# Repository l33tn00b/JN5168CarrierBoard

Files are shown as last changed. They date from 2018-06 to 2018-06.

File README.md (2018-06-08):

# JN5168CarrierBoard
Carrier Board for JN5168 Module with Reset and Programming Button; Step-Down Regulator (24V DC input).

This is a carrier board for JN5168 ZigBee modules. All pins are broken out. Reset and Programming buttons are provided. The better part of the carrier module is occupied by parts for the step-down voltage regulator. Reverse input polarity protection is provided (except for the input buffer capacitor, if placed). 

Above stated imput voltage limit (24V) depends on the FET used for polarity protection and the voltage rating of the input buffer capacitor. The chosen FET for polarity protection is rated for up to 30V. Omitting or replacing this FET and placing an appropriate buffer capacitor allow for input voltages up to the limit of the DC-DC step-down regulator, i.e. 45V.

Voltage is supplied via RIACON Connectors (screw terminals that may be pulled off from their pins).

Here is a representation created by KiCAD:

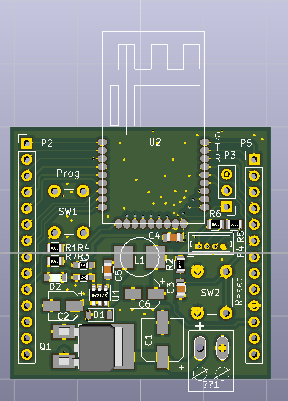
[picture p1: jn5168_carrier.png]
JN5168 Carrier Board Rendered by KiCAD Render of JN5168 Carrier Board


This is the schematic:
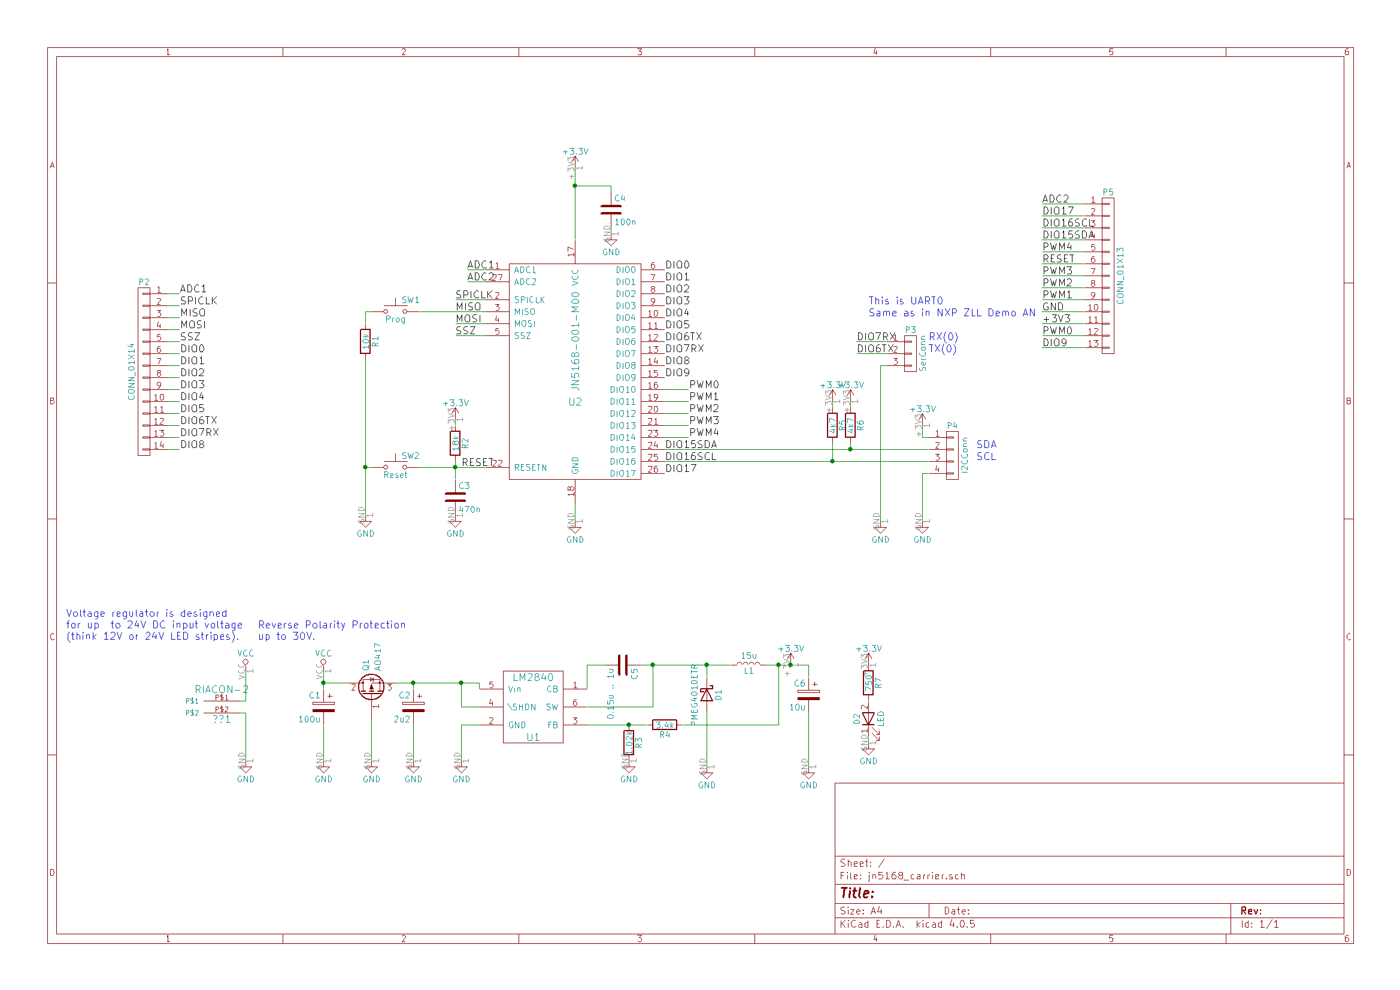
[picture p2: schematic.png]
JN5168 Carrier Board Schematic Schematic of JN5168 Carrier Board


There you go, a real PCB (to the left):
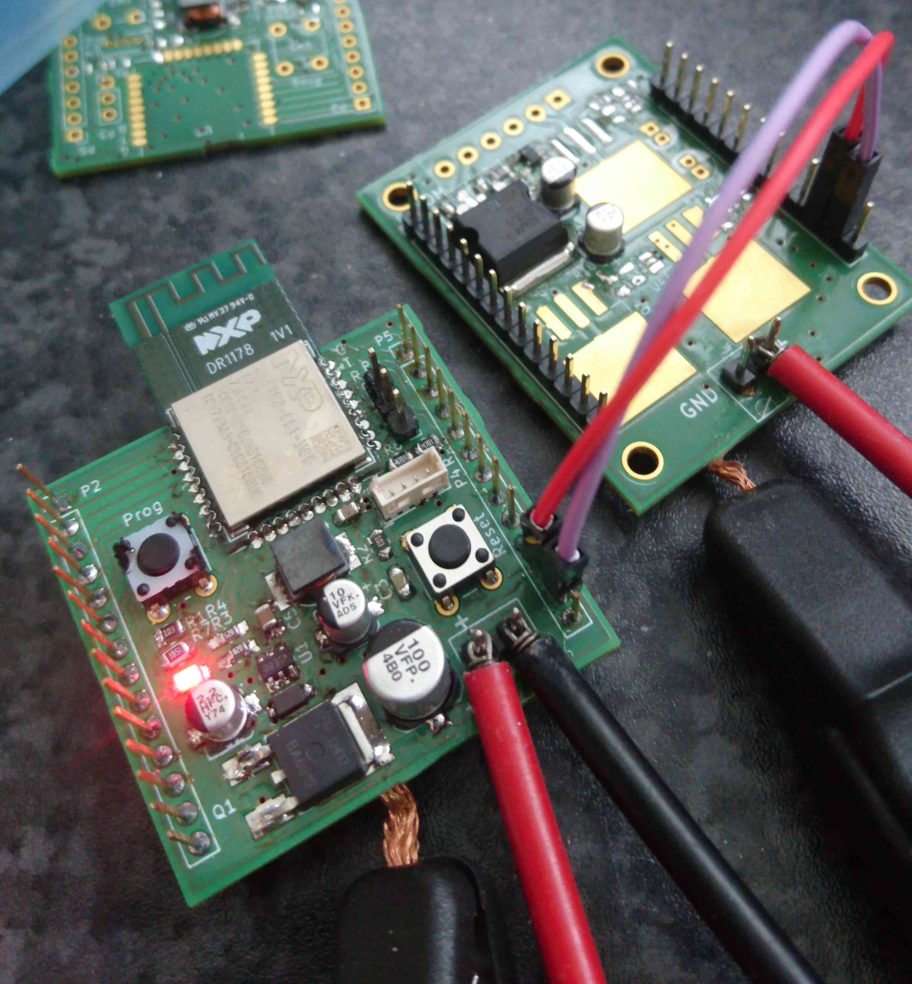
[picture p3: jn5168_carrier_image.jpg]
JN5168 Carrier Board Image Image of JN5168 Carrier Board


On the above picture you might realize the voltage supply (red and black) is done via clamps instead of the screw terminal: This is due to the RIACON screw terminal that can just be pulled off the solder pins.

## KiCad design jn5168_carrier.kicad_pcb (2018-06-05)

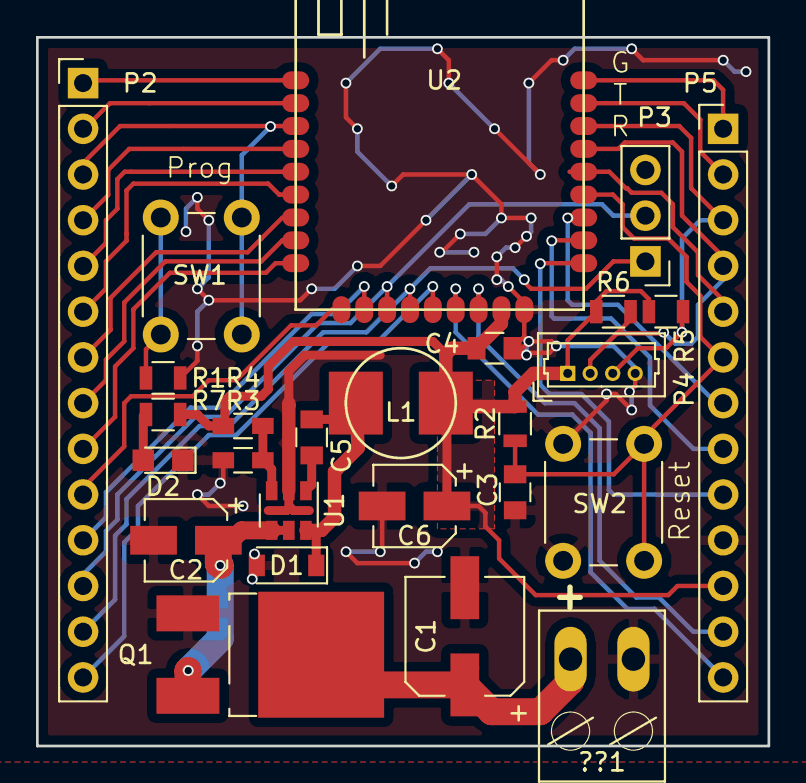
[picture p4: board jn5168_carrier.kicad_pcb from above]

Board: 2 copper layers, 40.6 x 39.4 mm, 26 parts (0 on the bottom side), 34 nets.

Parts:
??1: RIACON-2; con-riacon-RIACON-2
C1: 100u; CP_Elec_6.3x7.7
C2: 2u2; CP_Elec_4x5.8
C3: 470n; C_0805
C4: 100n; C_0805
C5: 0.15u .. 1u; C_0805
C6: 10u; CP_Elec_4x5.8
D1: PMEG4010ETR; D_SOD-123
D2: LED; LED_0805
L1: 15u; Murata_LQH55D
P2: CONN_01X14; Pin_Header_Straight_1x14_Pitch2.54mm
P3: SerConn; Pin_Header_Straight_1x03_Pitch2.54mm
P4: I2CConn; Molex_PicoBlade_53047-0410_04x1.25mm_Straight
P5: CONN_01X13; Pin_Header_Straight_1x13_Pitch2.54mm
Q1: AO417; TO-252-2Lead
R1: 10k; R_0805
R2: 18k; R_0805
R3: 1.02k; R_0603_HandSoldering
R4: 3.4k; R_0603_HandSoldering
R5, R6: 4k7; R_0805
R7: 750; R_0805
SW1: Prog; SW_PUSH_6mm
SW2: Reset; SW_PUSH_6mm
U1: LM2840; SOT-23-6
U2: JN5168-001-M00

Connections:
+3V3: C4.1, C6.1, L1.2, P4.1, P5.11, R2.1, R4.1, R5.1, R6.1, R7.1, U2.17
/ADC1: P2.1, U2.1
/ADC2: P5.1, U2.27
/DIO0: P2.6, U2.6
/DIO1: P2.7, U2.7
/DIO2: P2.8, U2.8
/DIO3: P2.9, U2.9
/DIO4: P2.10, U2.10
/DIO5: P2.11, U2.11
/DIO6TX: P2.12, P3.2, U2.12
/DIO7RX: P2.13, P3.1, U2.13
/DIO8: P2.14, U2.14
/DIO9: P5.13, U2.15
/DIO15SDA: P4.2, P5.4, R6.2, U2.24
/DIO16SCL: P4.3, P5.3, R5.2, U2.25
/DIO17: P5.2, U2.26
/MISO: P2.3, SW1.2, U2.3
/MOSI: P2.4, U2.4
/PWM0: P5.12, U2.16
/PWM1: P5.9, U2.19
/PWM2: P5.8, U2.20
/PWM3: P5.7, U2.21
/PWM4: P5.5, U2.23
/RESET: C3.1, P5.6, R2.2, SW2.2, U2.22
/SPICLK: P2.2, U2.2
/SSZ: P2.5, U2.5
GND: ??1.P$2, C1.2, C2.2, C3.2, C4.2, C6.2, D1.2, D2.1, P3.3, P4.4, P5.10, Q1.1, R1.2, R3.2, SW2.1, U1.2, U2.18
unnamed: C2.1, Q1.3, U1.4, U1.5
unnamed: C5.1, D1.1, L1.1, U1.6
unnamed: C5.2, U1.1
unnamed: D2.2, R7.2
unnamed: R1.1, SW1.1
unnamed: R3.1, R4.2, U1.3
VCC: ??1.P$1, C1.1, Q1.2
